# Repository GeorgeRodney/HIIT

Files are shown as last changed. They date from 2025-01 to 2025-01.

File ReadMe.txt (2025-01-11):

To Debug:
    - Flash it and have program running with stlink attached
    - open OPENODC: openocd -f interface/stlink.cfg -f target/stm32f4x.cfg
    - new terminal: gdb-multiarch build/Timer.elf
    - target extended-remote :3333
    - Add breakpoints and go

TODO:
    [D]: Make correct alternating SPRINT/REST Play sequence. 
    [D]: Add functionality to set seconds for SPRINT with butttons.
    []: Create seconds sound so the user knows where they are in the logic structure.
    []: Create a schematic on EasyEda
    []: Create Sound functions to replace // Announce comments
    []: Remove delay from PlayBuzzer()

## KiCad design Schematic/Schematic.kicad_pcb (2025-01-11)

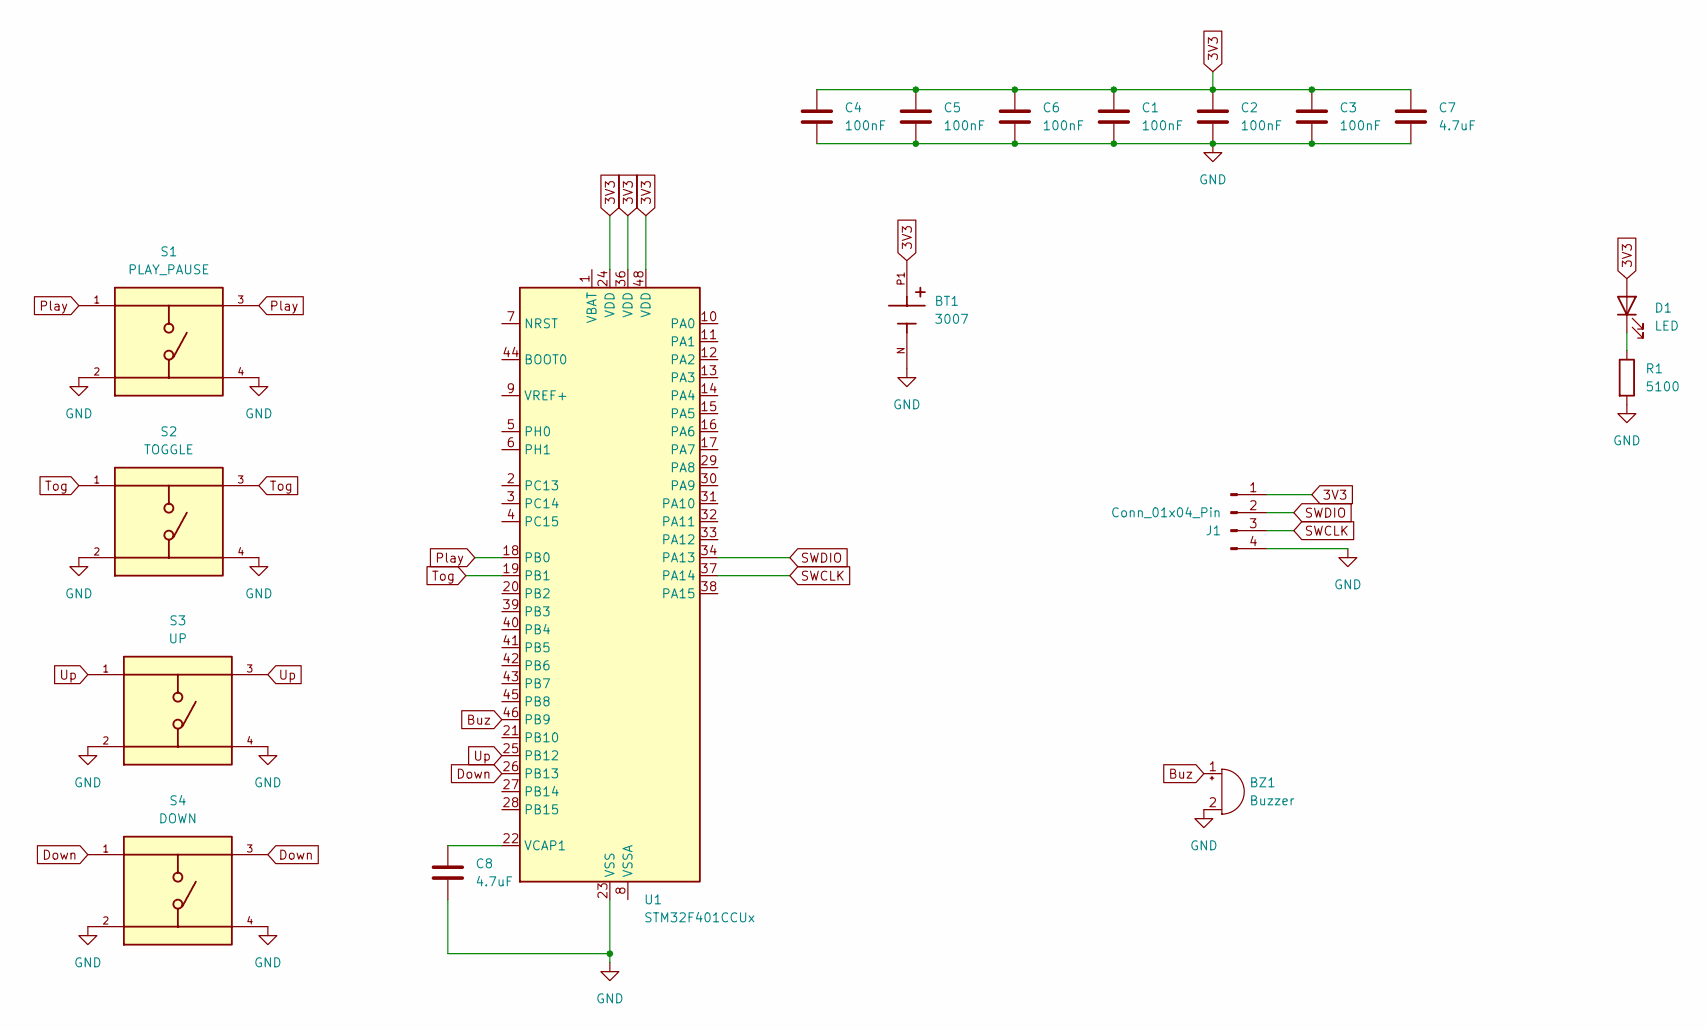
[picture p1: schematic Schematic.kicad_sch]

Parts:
BT1: 3007; BAT_3007; PARTREV M
BZ1: Buzzer; Buzzer_Mallory_AST1240MLQ
C1, C2, C3, C4, C5, C6: 100nF; C_0201_0603Metric
C7, C8: 4.7uF; C_0201_0603Metric
D1: LED; LED_0201_0603Metric
J1: Conn_01x04_Pin; PinHeader_1x04_P2.54mm_Horizontal
R1: 5100; R_0201_0603Metric
S1: PLAY_PAUSE; SW_TS04-66-73-BK-100-SMT; PARTREV 1.0
S2: TOGGLE; SW_TS04-66-73-BK-100-SMT; PARTREV 1.0
S3: UP; SW_TS04-66-73-BK-100-SMT; PARTREV 1.0
S4: DOWN; SW_TS04-66-73-BK-100-SMT; PARTREV 1.0
U1: STM32F401CCUx; QFN-48-1EP_7x7mm_P0.5mm_EP5.6x5.6mm

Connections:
3V3: BT1.P1, C1.1, C2.1, C3.1, C4.1, C5.1, C6.1, C7.1, D1.2 (A), J1.1, U1.24 (VDD), U1.36 (VDD), U1.48 (VDD)
Buz: BZ1.1 (+), U1.46 (PB9)
Down: S4.1, S4.3, U1.26 (PB13)
GND: BT1.N, BZ1.2 (-), C1.2, C2.2, C3.2, C4.2, C5.2, C6.2, C7.2, C8.2, J1.4, R1.2, S1.2, S1.4, S2.2, S2.4, S3.2, S3.4, S4.2, S4.4, U1.23 (VSS), U1.35 (VSS), U1.47 (VSS), U1.49 (VSS)
unnamed: D1.1 (K), R1.1
unnamed: C8.1, U1.22 (VCAP1)
Play: S1.1, S1.3, U1.18 (PB0)
SWCLK: J1.3, U1.37 (PA14)
SWDIO: J1.2, U1.34 (PA13)
Tog: S2.1, S2.3, U1.19 (PB1)
Up: S3.1, S3.3, U1.25 (PB12)

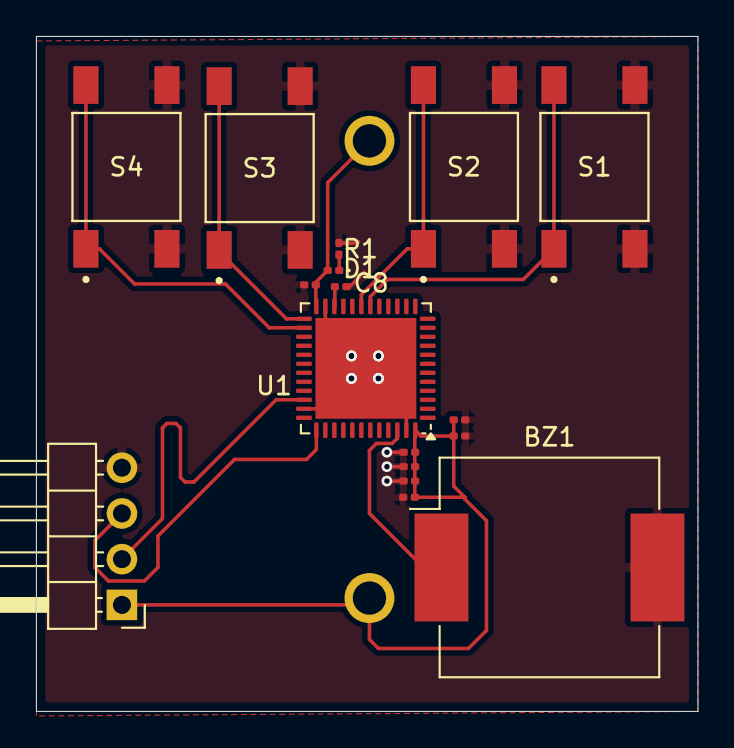
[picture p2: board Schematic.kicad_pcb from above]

Board: 2 copper layers, 36.8 x 37.5 mm, 18 parts (1 on the bottom side), 11 nets.

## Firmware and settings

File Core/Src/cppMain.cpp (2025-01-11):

#include "cppMain.hpp"
#include "main.h"
#include "stm32f4xx_hal.h"
#include <cstdio>
#include <cstring>

volatile uint32_t msCounter = 0;
volatile uint32_t timeInSeconds_ = 0;

uint32_t startPlayTime_;
uint32_t sprintStartTime_;
uint32_t sprintStopTime_;
uint32_t restStartTime_;
uint32_t restStopTime_;

uint32_t totalSprintTime_ = 2;
uint32_t totalRestTime_ = 4;

ButtonGPIOConfig buttonConfigs[BUTTON_COUNT] = {
  {PLAY_PAUSE_BUTTON, BUTTON_GPIO_PORT},
  {TOGGLE_BUTTON, BUTTON_GPIO_PORT},
  {UP_BUTTON, BUTTON_GPIO_PORT},
  {DOWN_BUTTON, BUTTON_GPIO_PORT}
};

uint32_t bCounter[BUTTON_COUNT] = {0};
uint8_t bPressed[BUTTON_COUNT] = {NOT_PRESSED};

SystemState sysState_ = PAUSE;
ExerciseState exercisePhase_ = REST;
Sounds soundState = SPRINT_BEEP;
MenuInterval selectState_ = SELECT_SPRINT;

void EventLoopCpp(void)
{
    ButtonPollingDebounced();

    // >-----------------------------------------------------------------------------------------<
    //
    //  CHECK FOR WHETHER OR NOT TO SWAP FROM SPRINT TO REST or REST TO SPRINT
    //  
    // >-----------------------------------------------------------------------------------------<
    if(sysState_ == PLAY)
    {   

      if(((timeInSeconds_ - sprintStartTime_) >= totalSprintTime_) && (exercisePhase_ == SPRINT))
      {
        restStartTime_ = timeInSeconds_;
        sprintStopTime_ = restStartTime_;
        exercisePhase_ = REST;
        HAL_GPIO_WritePin(USER_LED_GPIO_PORT, USER_LED_Pin, GPIO_PIN_RESET);
        PlayBuzzer(&htim11, REST_BEEP);
      }

      if(((timeInSeconds_ - restStartTime_) >= totalRestTime_) && (exercisePhase_ == REST))
      {
        sprintStartTime_ = timeInSeconds_;
        restStopTime_ = sprintStartTime_;
        exercisePhase_ = SPRINT;
        HAL_GPIO_WritePin(USER_LED_GPIO_PORT, USER_LED_Pin, GPIO_PIN_SET);
        PlayBuzzer(&htim11, SPRINT_BEEP);
      }
    }

}

extern "C"
{
    void EventLoopC()
    {
        HAL_TIM_Base_Start_IT(&htim10);

        while(true)
        {
            EventLoopCpp();
        }
    }

}

void PlayBuzzer(TIM_HandleTypeDef *htim, Sounds beep)
{   
    uint32_t frequency;

    if (beep == SPRINT_BEEP)
    {
        frequency = 4000;
    }
    else if (beep == REST_BEEP)
    {
        frequency = 1000;
    }
    else if (beep == PRESS_BEEP)
    {
        frequency = 200;
    }

    // Update the Timer Period for the desired frequency
    uint32_t timerClock = 84000000;  // 84 MHz APB1 Timer Clock
    uint32_t prescaler = htim->Init.Prescaler + 1;
    uint32_t period = (timerClock / (prescaler * frequency)) - 1;

    // Check validity and apply
    if (period <= 0xFFFF)  // Ensure within 16-bit timer range
    {
        __HAL_TIM_SET_AUTORELOAD(htim, period);
        __HAL_TIM_SET_COMPARE(htim, TIM_CHANNEL_1, period / 2);  // 50% Duty Cycle
        HAL_TIM_PWM_Start(htim, TIM_CHANNEL_1);  // Start PWM
        HAL_Delay(BUZZER_LENGTH);  // Play for 500 ms
        HAL_TIM_PWM_Stop(htim, TIM_CHANNEL_1);  // Stop PWM
    }
}

void ButtonPollingDebounced(void)
{
  for(Buttons button = PLAY_PAUSE; button < BUTTON_COUNT; button = static_cast<Buttons>(button + 1))
  {
    
    // Increment or decrement the button counter
    GPIO_PinState pressResult =  HAL_GPIO_ReadPin(buttonConfigs[button].port, buttonConfigs[button].pin);
    if( (pressResult == LOW) && (bCounter[button] < COUNTER_MAX))
    {
      bCounter[button]++;
    }
    else if ((pressResult == HIGH) && (bCounter[button] > COUNTER_MIN))
    {
      bCounter[button]--;
    }

    // Check transition: NOT_PRESSED -> PRESSED?
    if((bCounter[button] > PRESSED_COUNT) && 
          (bPressed[button] == NOT_PRESSED))
    {
      bPressed[button] = PRESSED;
      ExecutePress(button);
    }

    // Check transition: PRESSED -> NOT_PRESSED?
    if((bCounter[button] < NOT_PRESSED_COUNT) &&
          (bPressed[button] == PRESSED))
    {
      bPressed[button] = NOT_PRESSED;
    }

  }

}

void ExecutePress(Buttons button)
{
  switch (button){

    case PLAY_PAUSE: // PLAY/PAUSE BUTTON
      if (sysState_ == PAUSE)
      {
        // START_WORKOUT()
        HAL_GPIO_WritePin(USER_LED_GPIO_PORT, USER_LED_Pin, GPIO_PIN_SET);

        // BEGIN SPRINT and TIMING
        restStopTime_ = timeInSeconds_;
        sprintStartTime_ = restStopTime_;
        exercisePhase_ = SPRINT;
        PlayBuzzer(&htim11,SPRINT_BEEP);

        sysState_ = PLAY;
      }
      else if (sysState_ == PLAY)
      {
        // PAUSE_MENU()
        HAL_GPIO_WritePin(USER_LED_GPIO_PORT, USER_LED_Pin, GPIO_PIN_RESET);
        sysState_ = PAUSE;

      }

      // WriteState(sysState_);

      break;
    
    case TOGGLE: // TOGGLE SPRINT/RELAX
      if (sysState_ == PLAY)
      {
        break;
      }

      ToggleSprintRestState();
      HAL_GPIO_TogglePin(USER_LED_GPIO_PORT, USER_LED_Pin);
      PlayBuzzer(&htim11, PRESS_BEEP);

      // DO SOMETHING IF IN PAUSE
      break;

    case SEC_UP: // SECONDS UP
      if (sysState_ == PLAY)
      {
        break;
      }

      IncrementIntervalInSecs();
      HAL_GPIO_TogglePin(USER_LED_GPIO_PORT, USER_LED_Pin);
      PlayBuzzer(&htim11, PRESS_BEEP);

      // DO SOMETHING IF IN PAUSE
      break;

    case SEC_DOWN: // SECONDS DOWN
      if (sysState_ == PLAY)
      {
        break;
      }

      DecrementIntervalInSecs();
      HAL_GPIO_TogglePin(USER_LED_GPIO_PORT, USER_LED_Pin);
      PlayBuzzer(&htim11, PRESS_BEEP);
      // DO SOMETHING IF IN PAUSE
      break;

    default:
      break;
  }
}

// extern "C"{
void ToggleSprintRestState(void)
{
  if (selectState_ == SELECT_SPRINT)
  {
    selectState_ = SELECT_REST;
    // Annouce Select State
  }
  else if (selectState_ == SELECT_REST)
  {
    selectState_ = SELECT_SPRINT;
    // Announce Select State
  }
}
// }

// extern "C"{
void IncrementIntervalInSecs(void)
{
  // INCREMENT
  if (selectState_ == SELECT_SPRINT)
  {
    // Announce SPRINT
    if (totalSprintTime_ < SPRINT_UP_LIM)
    {
      totalSprintTime_++;
    }

  }
  else if (selectState_ == SELECT_REST)
  {
    //Announce REST
    if (totalRestTime_ < REST_UP_LIM)
    {
      totalRestTime_++;
    }
  }

  // // APPLY  LIMITS
  // if (totalSprintTime_ > SPRINT_UP_LIM)
  // {
  //   totalSprintTime_ = SPRINT_UP_LIM;
  //   // Announce upper limit reached
  // }

  // if (totalRestTime_ > REST_UP_LIM)
  // {
  //   totalRestTime_ = REST_UP_LIM;
  //   // Announce upper limit reached
  // }
}
// }

// extern "C"{
void DecrementIntervalInSecs(void)
{
  // INCREMENT
  if (selectState_ == SELECT_SPRINT)
  {
    // Announce SPRINT
    if (totalSprintTime_ > SPRINT_LOW_LIM)
    {
      totalSprintTime_--;
    }
  }
  else if (selectState_ == SELECT_REST)
  {
    //Announce REST
    if (totalRestTime_ > REST_LOW_LIM)
    {
      totalRestTime_--;
    }
  }

  // // APPLY  LIMITS
  // if (totalSprintTime_ < SPRINT_LOW_LIM)
  // {
  //   totalSprintTime_ = SPRINT_LOW_LIM;
  //   // Announce upper limit reached
  // }

  // if (totalRestTime_ < REST_LOW_LIM)
  // {
  //   totalRestTime_ = REST_LOW_LIM;
  //   // Announce upper limit reached
  // }
}
// }

void HAL_TIM_PeriodElapsedCallback(TIM_HandleTypeDef *htim10)
{
    if (htim10->Instance == TIM10) {
        msCounter++;

        if(msCounter % 1000 == 0)
        {
          timeInSeconds_++;

          // I dont think I need this.
          // The seconds will run for 138 years
          // if (timeInSeconds_ >= 4294967295)
          // {
          //   timeInSeconds_ = 0;
          // }
        }
    }
}

void TIM10_IRQHandler(void)
{
    HAL_TIM_IRQHandler(&htim10);
}

void WriteState(SystemState state)
{
    char buffer[10];

    if (state == PLAY)
    {
      strcpy(buffer,"PLAY\r\n");
    }else if (state == PAUSE)
    {
      strcpy(buffer,"PAUSE\r\n");
    }else
    {
      strcpy(buffer, "Default\r\n");
    }

    HAL_UART_Transmit(&huart1, (uint8_t *)buffer, strlen(buffer), HAL_MAX_DELAY);
}

void WriteNum(uint32_t time)
{
    char buffer[14];
    sprintf(buffer, "%lu\r\n", (unsigned long)time);
    HAL_UART_Transmit(&huart1, (uint8_t *)buffer, strlen(buffer), HAL_MAX_DELAY);
}

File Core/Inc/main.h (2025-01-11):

/**
******************************************************************************
* @file           : main.h
* @brief          : Header for main.c file.
*                   This file contains the common defines of the application.
******************************************************************************
* @attention
*
* Copyright (c) 2024 STMicroelectronics.
* All rights reserved.
*
* This software is licensed under terms that can be found in the LICENSE file
* in the root directory of this software component.
* If no LICENSE file comes with this software, it is provided AS-IS.
*
******************************************************************************
*/

#ifndef __MAIN_H
#define __MAIN_H

#ifdef __cplusplus
extern "C" {
#endif

#include "stm32f4xx_hal.h"
#include <stdint.h>
#include "stm32f401xc.h"


void Error_Handler(void);

#define USER_LED_Pin GPIO_PIN_14
#define RUN_LED GPIO_PIN_15
#define USER_LED_GPIO_PORT GPIOC
#define PLAY_PAUSE_BUTTON GPIO_PIN_0
#define BUTTON_GPIO_PORT GPIOB
#define TOGGLE_BUTTON GPIO_PIN_1
#define UP_BUTTON GPIO_PIN_12
#define DOWN_BUTTON GPIO_PIN_13

#define LOW 0
#define HIGH 1
#define BUTTON_COUNT 4
#define PRESSED 1
#define NOT_PRESSED 0
#define PRESSED_COUNT 12500
#define NOT_PRESSED_COUNT 2500
#define COUNTER_MAX 15000
#define COUNTER_MIN 0
#define SPRINT_UP_LIM 60
#define SPRINT_LOW_LIM 2
#define REST_UP_LIM 60
#define REST_LOW_LIM 2
#define BUZZER_LENGTH 100

extern TIM_HandleTypeDef htim10;
extern TIM_HandleTypeDef htim11;
extern UART_HandleTypeDef huart1;

typedef struct {
  uint16_t pin;
  GPIO_TypeDef* port;
} ButtonGPIOConfig;

typedef enum {
  PLAY = 0,
  PAUSE
} SystemState;

typedef enum {
  PLAY_PAUSE = 0,
  TOGGLE,
  SEC_UP,
  SEC_DOWN
} Buttons;

typedef enum {
  SPRINT_BEEP = 0,
  REST_BEEP,
  PRESS_BEEP
} Sounds;

typedef enum {
  SPRINT = 0,
  REST
} ExerciseState;

typedef enum {
  SELECT_SPRINT = 0,
  SELECT_REST
} MenuInterval;

extern ButtonGPIOConfig buttonConfigs[BUTTON_COUNT];
extern uint32_t  bCounter[BUTTON_COUNT];
extern uint8_t  bPressed[BUTTON_COUNT];

#ifdef __cplusplus
}
#endif

#endif /* __MAIN_H */

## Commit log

2024-12-31 PWM working. PLAY state working
2024-12-31 UART defined
2024-12-31 UART working now
2025-01-01 Writing to UART is F ing with my logic
2025-01-02 All 4 buttons working. User can change the timing
2025-01-02 Added Schematic
    [Schematic.kicad_pcb, Schematic.kicad_sch]
2025-01-11 Debugging totalSprintTime_
    [Schematic.kicad_pcb, Schematic.kicad_sch]
2025-01-11 Schematic stuff
    [Schematic.kicad_pcb, Schematic.kicad_sch]
